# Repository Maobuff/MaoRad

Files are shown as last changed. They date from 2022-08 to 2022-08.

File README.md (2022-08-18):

# MadRad
## My(maobuff) attempt at catching gamma photons.

# [Schemaic](doc/schematic.pdf)

# Remarks:
Increasing diode count doesn't improve sensitivity (TODO: check with comparator and counter).

Scintillator crystal is a MUST to improve sensitivity to be able to register natural radiation photons.

I highly recommend replacing BPW34 with a bigger diode with more surface area. For example, FirstSensor is manufacturing PIN diodes with a build-in scintillator.

Probably losing some gain to LMC662 bandwidth.

# What next?
```
Add a guard ring to the second stage on the PCB.
Improve sensitivity
Add comparator and counter
Sound or light effects
Improve SNR
Increase gain
Spectrometry
```

## Device assembled
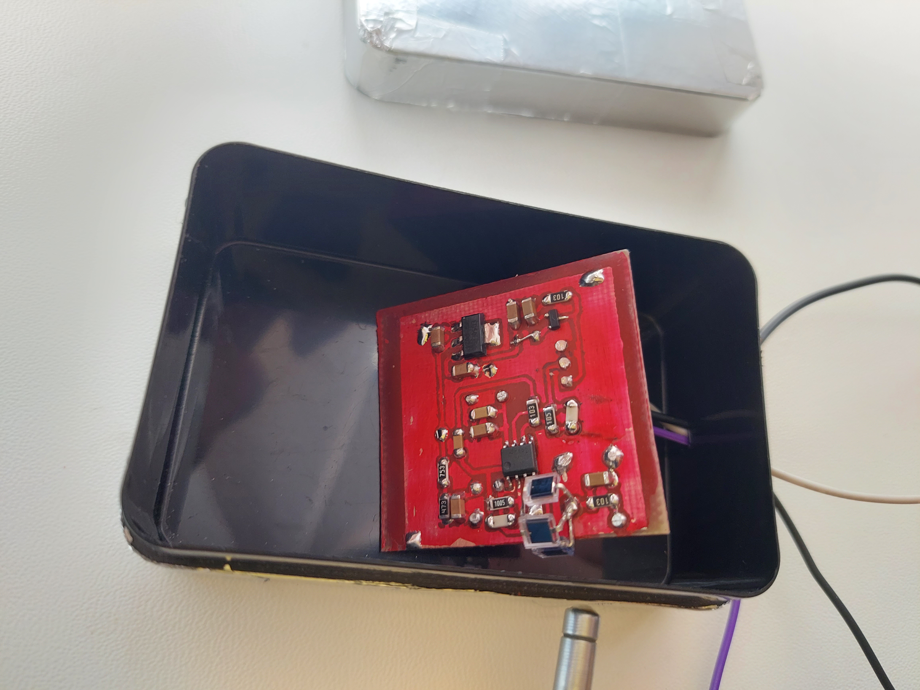
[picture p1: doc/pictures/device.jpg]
Device


## Output waveform example from Radium-226
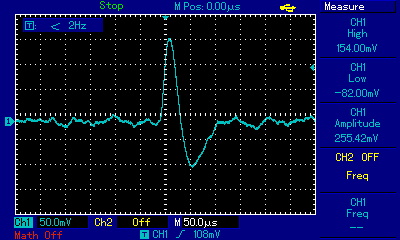
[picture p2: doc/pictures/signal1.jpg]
Signal


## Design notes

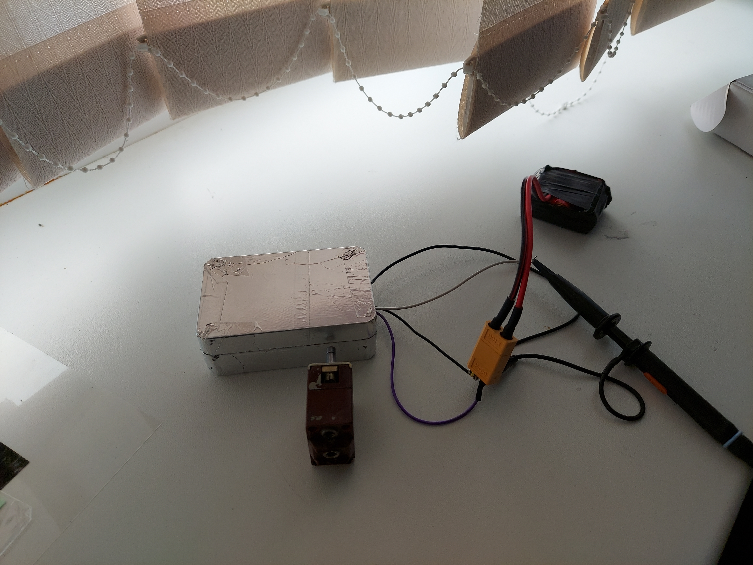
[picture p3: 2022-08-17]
doc/pictures/measuring.jpg

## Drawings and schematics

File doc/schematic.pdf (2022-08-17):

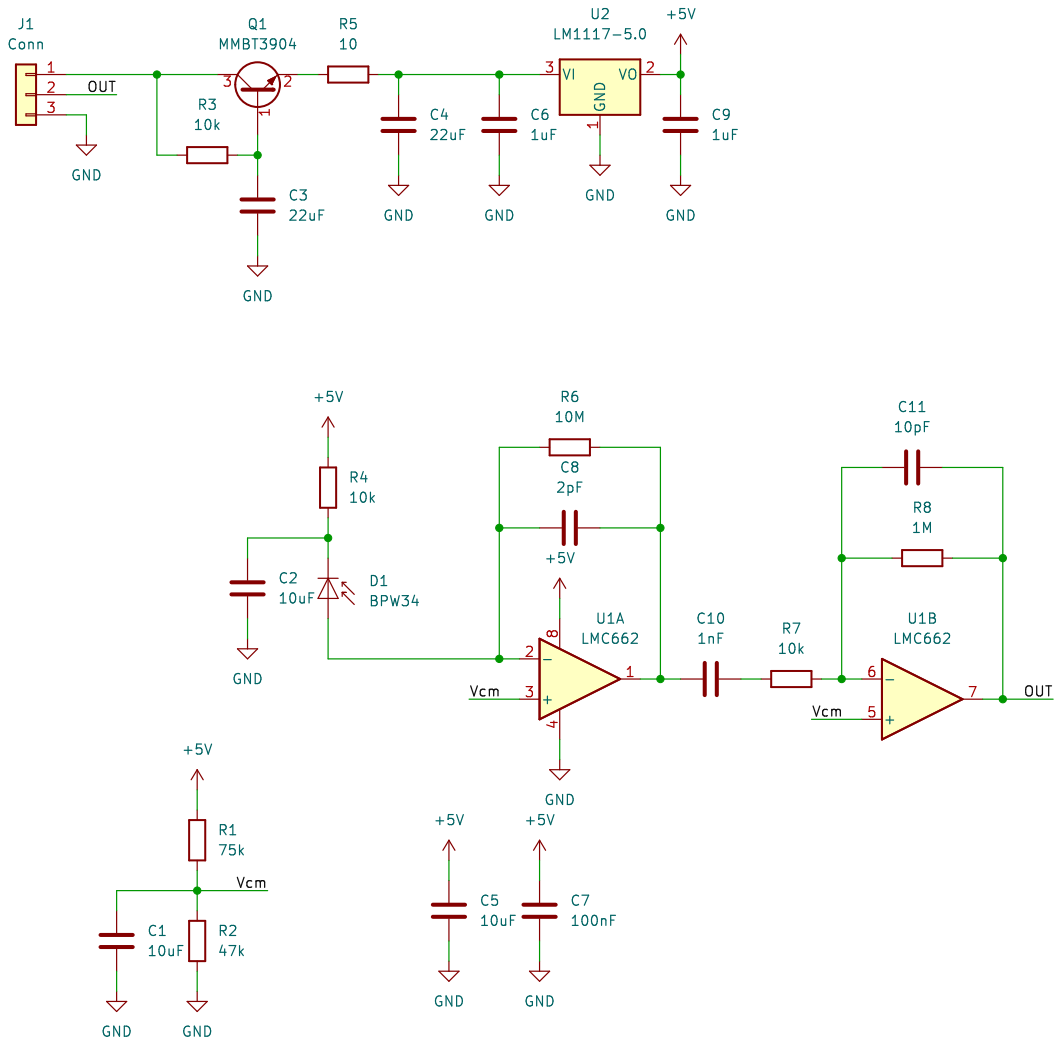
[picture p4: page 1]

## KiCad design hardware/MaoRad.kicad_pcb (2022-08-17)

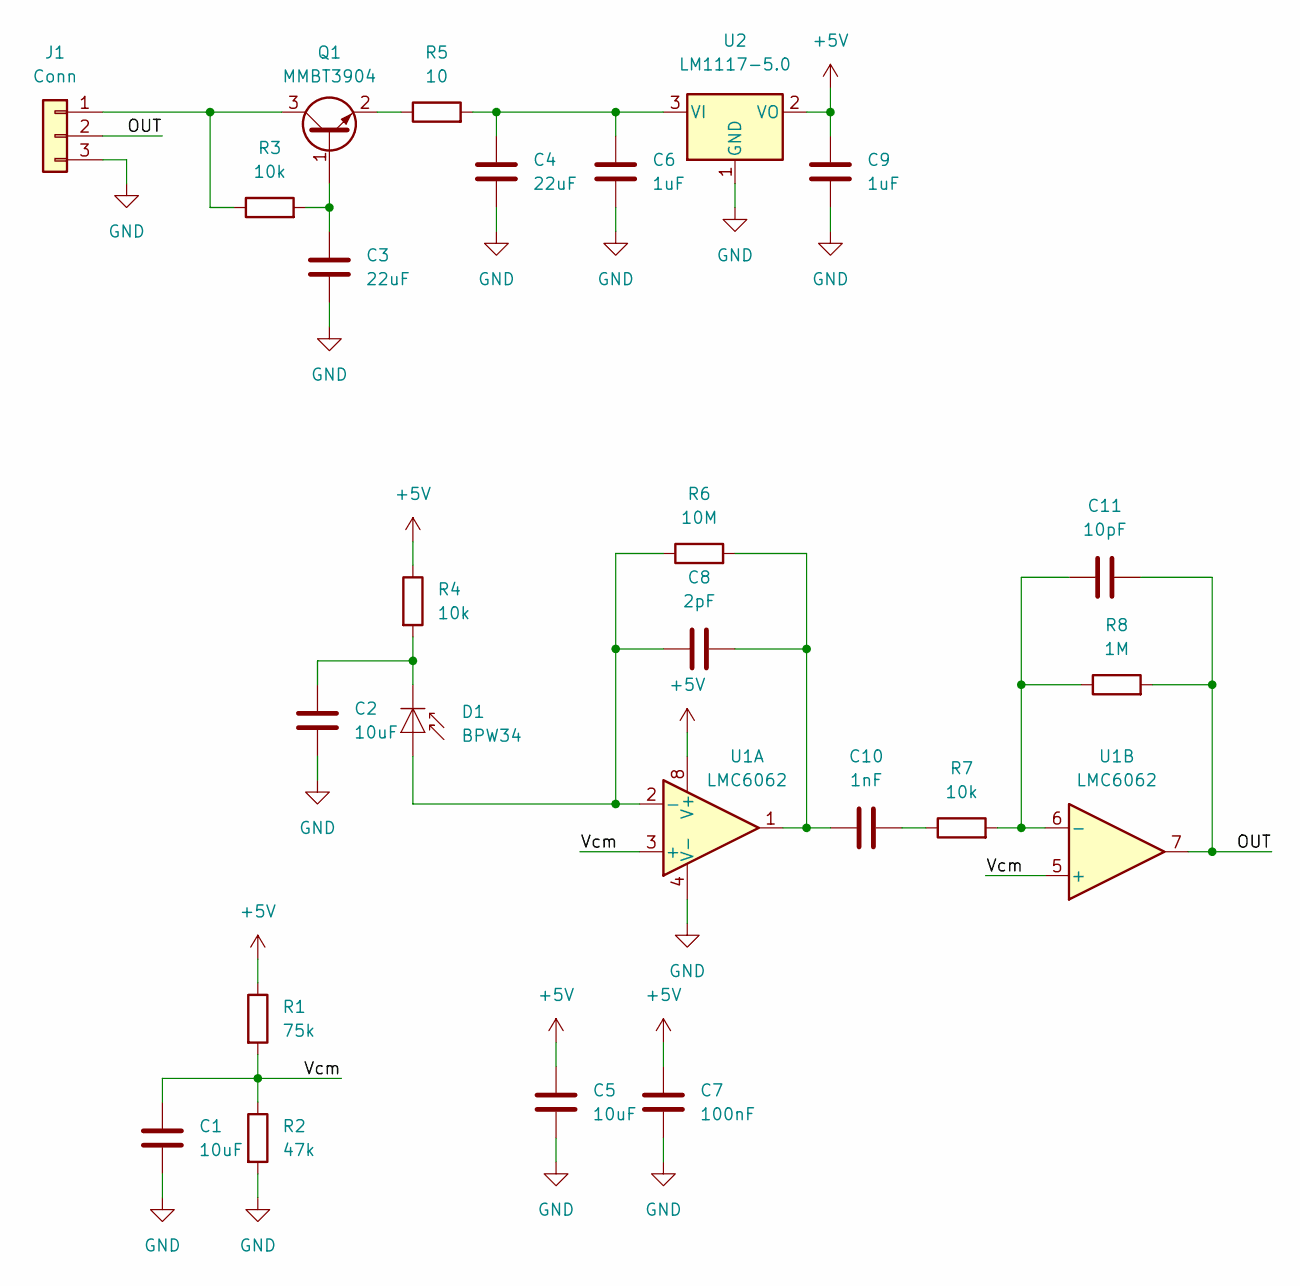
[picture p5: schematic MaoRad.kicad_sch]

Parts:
C1, C2, C5: 10uF; C_1206_3216Metric_Pad1.33x1.80mm_HandSolder
C3, C4: 22uF; C_1206_3216Metric_Pad1.33x1.80mm_HandSolder
C6, C9: 1uF; C_1206_3216Metric_Pad1.33x1.80mm_HandSolder
C7: 100nF; C_1206_3216Metric_Pad1.33x1.80mm_HandSolder
C8: 2pF; C_1206_3216Metric_Pad1.33x1.80mm_HandSolder
C10: 1nF; C_1206_3216Metric_Pad1.33x1.80mm_HandSolder
C11: 10pF; C_1206_3216Metric_Pad1.33x1.80mm_HandSolder
D1: BPW34; Osram_SMD-DIL2_4.5x4.0mm
J1: Conn; PinHeader_1x03_P2.54mm_Horizontal
Q1: MMBT3904; SOT-23
R1: 75k; R_1206_3216Metric_Pad1.30x1.75mm_HandSolder
R2: 47k; R_1206_3216Metric_Pad1.30x1.75mm_HandSolder
R3, R4, R7: 10k; R_1206_3216Metric_Pad1.30x1.75mm_HandSolder
R5: 10; R_1206_3216Metric_Pad1.30x1.75mm_HandSolder
R6: 10M; R_1206_3216Metric_Pad1.30x1.75mm_HandSolder
R8: 1M; R_1206_3216Metric_Pad1.30x1.75mm_HandSolder
U1: LMC6062
U2: LM1117-5.0; SOT-223-3_TabPin2

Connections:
+5V: C5.1, C7.1, C9.1, R1.1, R4.1, U1.8 (V+), U2.2 (VO)
/OUT: C11.2, J1.2, R8.2, U1.7
/Vcm: C1.1, R1.2, R2.1, U1.3 (+), U1.5 (+)
GND: C1.2, C2.2, C3.2, C4.2, C5.2, C6.2, C7.2, C9.2, J1.3, R2.2, U1.4 (V-), U2.1 (GND)
unnamed: C2.1, D1.1 (K), R4.2
unnamed: C3.1, Q1.1 (B), R3.2
unnamed: C4.1, C6.1, R5.2, U2.3 (VI)
unnamed: C8.1, D1.2 (A), R6.1, U1.2 (-)
unnamed: C8.2, C10.1, R6.2, U1.1
unnamed: C10.2, R7.1
unnamed: C11.1, R7.2, R8.1, U1.6 (-)
unnamed: J1.1, Q1.3 (C), R3.1
unnamed: Q1.2 (E), R5.1

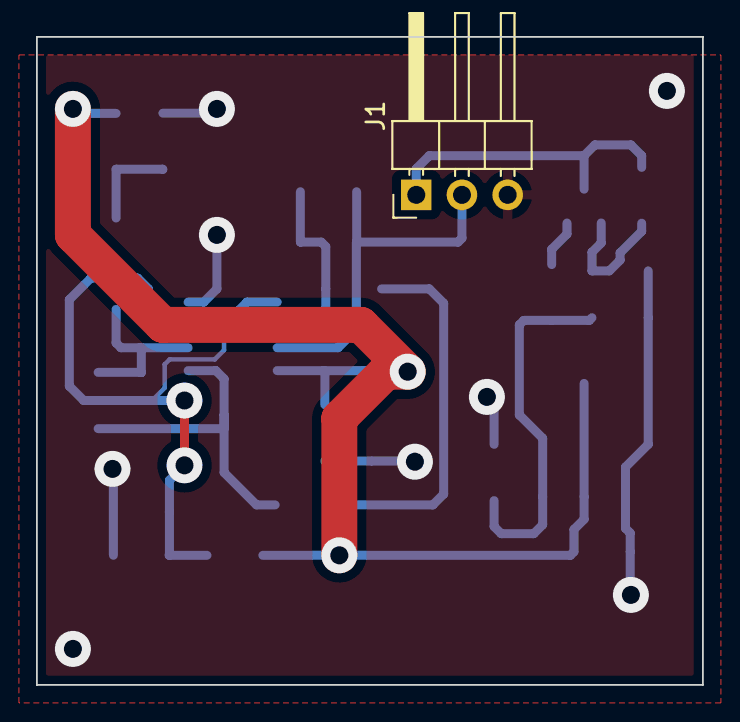
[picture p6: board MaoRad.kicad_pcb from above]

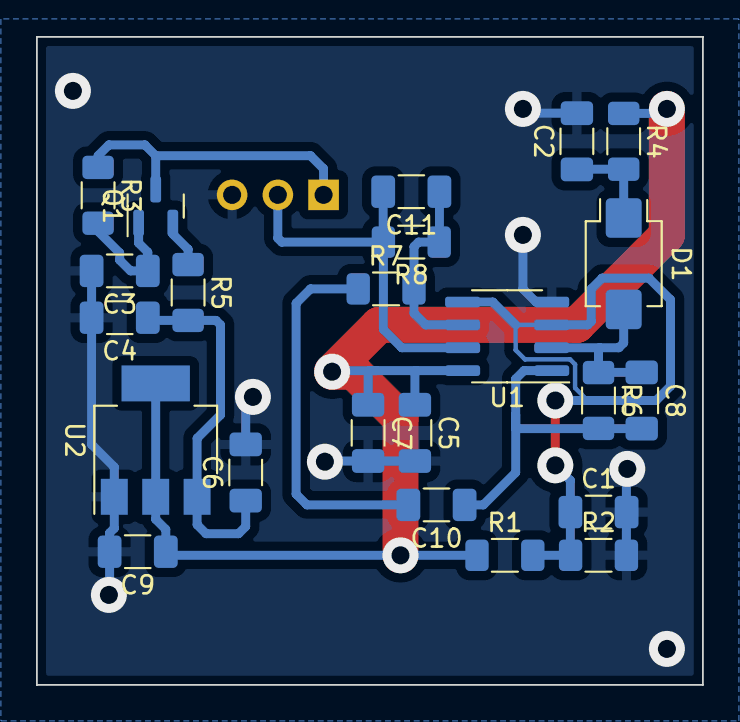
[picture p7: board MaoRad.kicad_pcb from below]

Board: 2 copper layers, 37.0 x 36.0 mm, 24 parts (23 on the bottom side), 13 nets.

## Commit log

2022-08-17 feat: init
    [MaoRad.kicad_pcb, MaoRad.kicad_sch]
2022-08-17 fix: lmc662
    [MaoRad.kicad_sch]
